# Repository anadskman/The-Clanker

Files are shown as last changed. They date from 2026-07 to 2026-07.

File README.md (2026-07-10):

# The Clanker

# 

# **The Clanker** is a fully custom mechanical keyboard designed from scratch using **KiCad** for the electronics and **Fusion 360** for the case. The goal of this project was to design every part of the keyboard myself, from the schematic and PCB layout to the enclosure and firmware.

The keyboard features a compact 68-key layout, per-key RGB lighting, a rotary encoder, and a 0.91" OLED display, all powered by a Raspberry Pi Pico.

## Features

* 68-key custom layout

* Raspberry Pi Pico (USB-C)

* MX switches

* Per-key SK6812 MINI-E RGB lighting

* Rotary encoder

* 0.91" I²C OLED display

* Custom 3D-printable case

* Designed entirely from scratch

## Design Process
The project began by creating the keyboard layout and designing the schematic in KiCad. After assigning footprints, the PCB was laid out and routed, including the switch matrix, RGB LEDs, OLED display, rotary encoder, and power circuitry.
Once the PCB was complete, it was exported into Fusion 360 where the enclosure was designed around it. The case was built specifically for 3D printing and split into two halves so it could fit on a smaller print bed while remaining rigid once assembled.

## BOM

| Item | Qty | Notes | $ | URL |
| --- | --: | --- | :--:  | ---- |
| Raspberry Pi Pico | 1 | RP2040 microcontroller | 9.23  | [link](https://www.aliexpress.com/item/1005011871301955.html?pdp_ext_f=%7B"order"%3A"19"%2C"eval"%3A"1"%2C"fromPage"%3A"search"%7D) |
| MX Mechanical Switches |  68 | Cherry MX compatible | 30.22 | [link](https://www.aliexpress.com/item/1005008998414457.html?pdp_ext_f=%7B"order"%3A"322"%2C"eval"%3A"1"%2C"fromPage"%3A"search"%7D) |
| PCB Mount Stabilizers  | 4 | For larger keys | 11.23 | [link](https://www.aliexpress.com/item/1005001686299616.html?pdp_ext_f=%7B"order"%3A"267"%2C"eval"%3A"1"%2C"fromPage"%3A"search"%7D) |
| LEDs |  68 | One per switch | 8.68 | [link](https://www.aliexpress.com/item/1005006727416963.html?pdp_ext_f=%7B"order"%3A"59"%2C"spu_best_type"%3A"price"%2C"eval"%3A"1"%2C"fromPage"%3A"search"%7D) |
| Keycap Set | 1 | 68-key compatible | 24.17 | [link](https://www.aliexpress.com/item/1005007252695395.html?pdp_ext_f=%7B"order"%3A"68"%2C"eval"%3A"1"%2C"fromPage"%3A"search"%7D) |
| Rotary Encoder | 1 | EC11 | 9.84 | [link](https://www.aliexpress.com/item/1005011653314162.html?pdp_ext_f=%7B"order"%3A"8"%2C"eval"%3A"1"%2C"fromPage"%3A"search"%7D) |
| Encoder Knob | 1 | Fits encoder shaft | 1.76 | [link](https://www.aliexpress.com/item/1005008291630040.html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"order"%3A"224"%2C"spu_best_type"%3A"price"%2C"eval"%3A"1"%2C"fromPage"%3A"search"%7D&search_p4p_id=20260710071720613074789560480005766622_6) |
| OLED Display | 1 | .91" I2C (SSD1306) | 1.44 | [link](https://www.aliexpress.com/item/1005008997559133.html?pdp_ext_f=%7B"order"%3A"2411"%2C"eval"%3A"1"%2C"fromPage"%3A"search"%7D) |
| PCB | 1 | Custom keyboard PCB | 61.97 | [link](https://github.com/user-attachments/assets/7c825ecb-10aa-4597-84ef-201b4d64e1a1) |
|  |  |  *Shipping* |  *5.71* | |
|  |  |  *Dutes* |  *8.27* |  |
|  |  | **Total** |  **109.56** | |

## Gallery

| PCB | Schematic | CAD Model |
| :---: | :---: | :---: |
|  |  |  |

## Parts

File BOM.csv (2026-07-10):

Item | Quantity | Notes | Price (USD) | URL
Raspberry Pi Pico | 1 | RP2040 microcontroller | 9.23 | https://www.aliexpress.com/item/1005011871301955.html?pdp_ext_f=%7B"order"%3A"19"%2C"eval"%3A"1"%2C"fromPage"%3A"search"%7D
MX Mechanical Switches | 68 | Cherry MX compatible | 30.22 | https://www.aliexpress.com/item/1005008998414457.html?pdp_ext_f=%7B"order"%3A"322"%2C"eval"%3A"1"%2C"fromPage"%3A"search"%7D
PCB Mount Stabilizers | 4 | For larger keys | 11.23 | https://www.aliexpress.com/item/1005001686299616.html?pdp_ext_f=%7B"order"%3A"267"%2C"eval"%3A"1"%2C"fromPage"%3A"search"%7D
LEDs | 68 | One per switch | 8.68 | https://www.aliexpress.com/item/1005006727416963.html?pdp_ext_f=%7B"order"%3A"59"%2C"spu_best_type"%3A"price"%2C"eval"%3A"1"%2C"fromPage"%3A"search"%7D
Keycap Set | 1 | 68-key compatible | 24.17 | https://www.aliexpress.com/item/1005007252695395.html?pdp_ext_f=%7B"order"%3A"68"%2C"eval"%3A"1"%2C"fromPage"%3A"search"%7D
Rotary Encoder | 1 | EC11 | 9.84 | https://www.aliexpress.com/item/1005011653314162.html?pdp_ext_f=%7B"order"%3A"8"%2C"eval"%3A"1"%2C"fromPage"%3A"search"%7D
Encoder Knob | 1 | Fits encoder shaft | 1.76 | https://www.aliexpress.com/item/1005008291630040.html?pdp_ext_f=%7B"order"%3A"224"%2C"spu_best_type"%3A"price"%2C"eval"%3A"1"%2C"fromPage"%3A"search"%7D&search_p4p_id=20260710071720613074789560480005766622_6
OLED Display | 1 | 0.91" I2C (SSD1306) | 1.44 | https://www.aliexpress.com/item/1005008997559133.html?pdp_ext_f=%7B"order"%3A"2411"%2C"eval"%3A"1"%2C"fromPage"%3A"search"%7D
PCB | 1 | Custom keyboard PCB | 61.97 | https://github.com/user-attachments/assets/7c825ecb-10aa-4597-84ef-201b4d64e1a1
 |  | Shipping | 5.71
 |  | Duties | 8.27
 |  | Total | 109.56

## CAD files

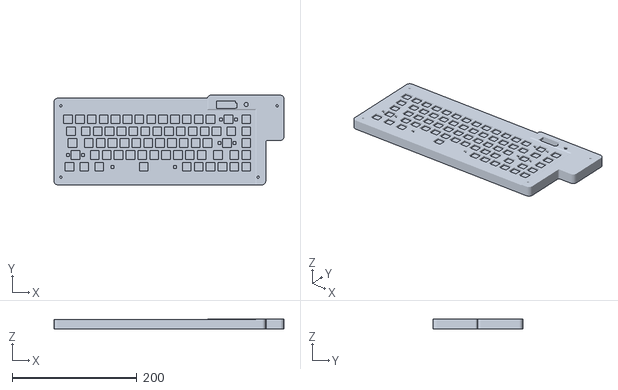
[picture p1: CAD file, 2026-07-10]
CAD/The Clanker Left Base.stl
368.9 x 143.8 x 16.0

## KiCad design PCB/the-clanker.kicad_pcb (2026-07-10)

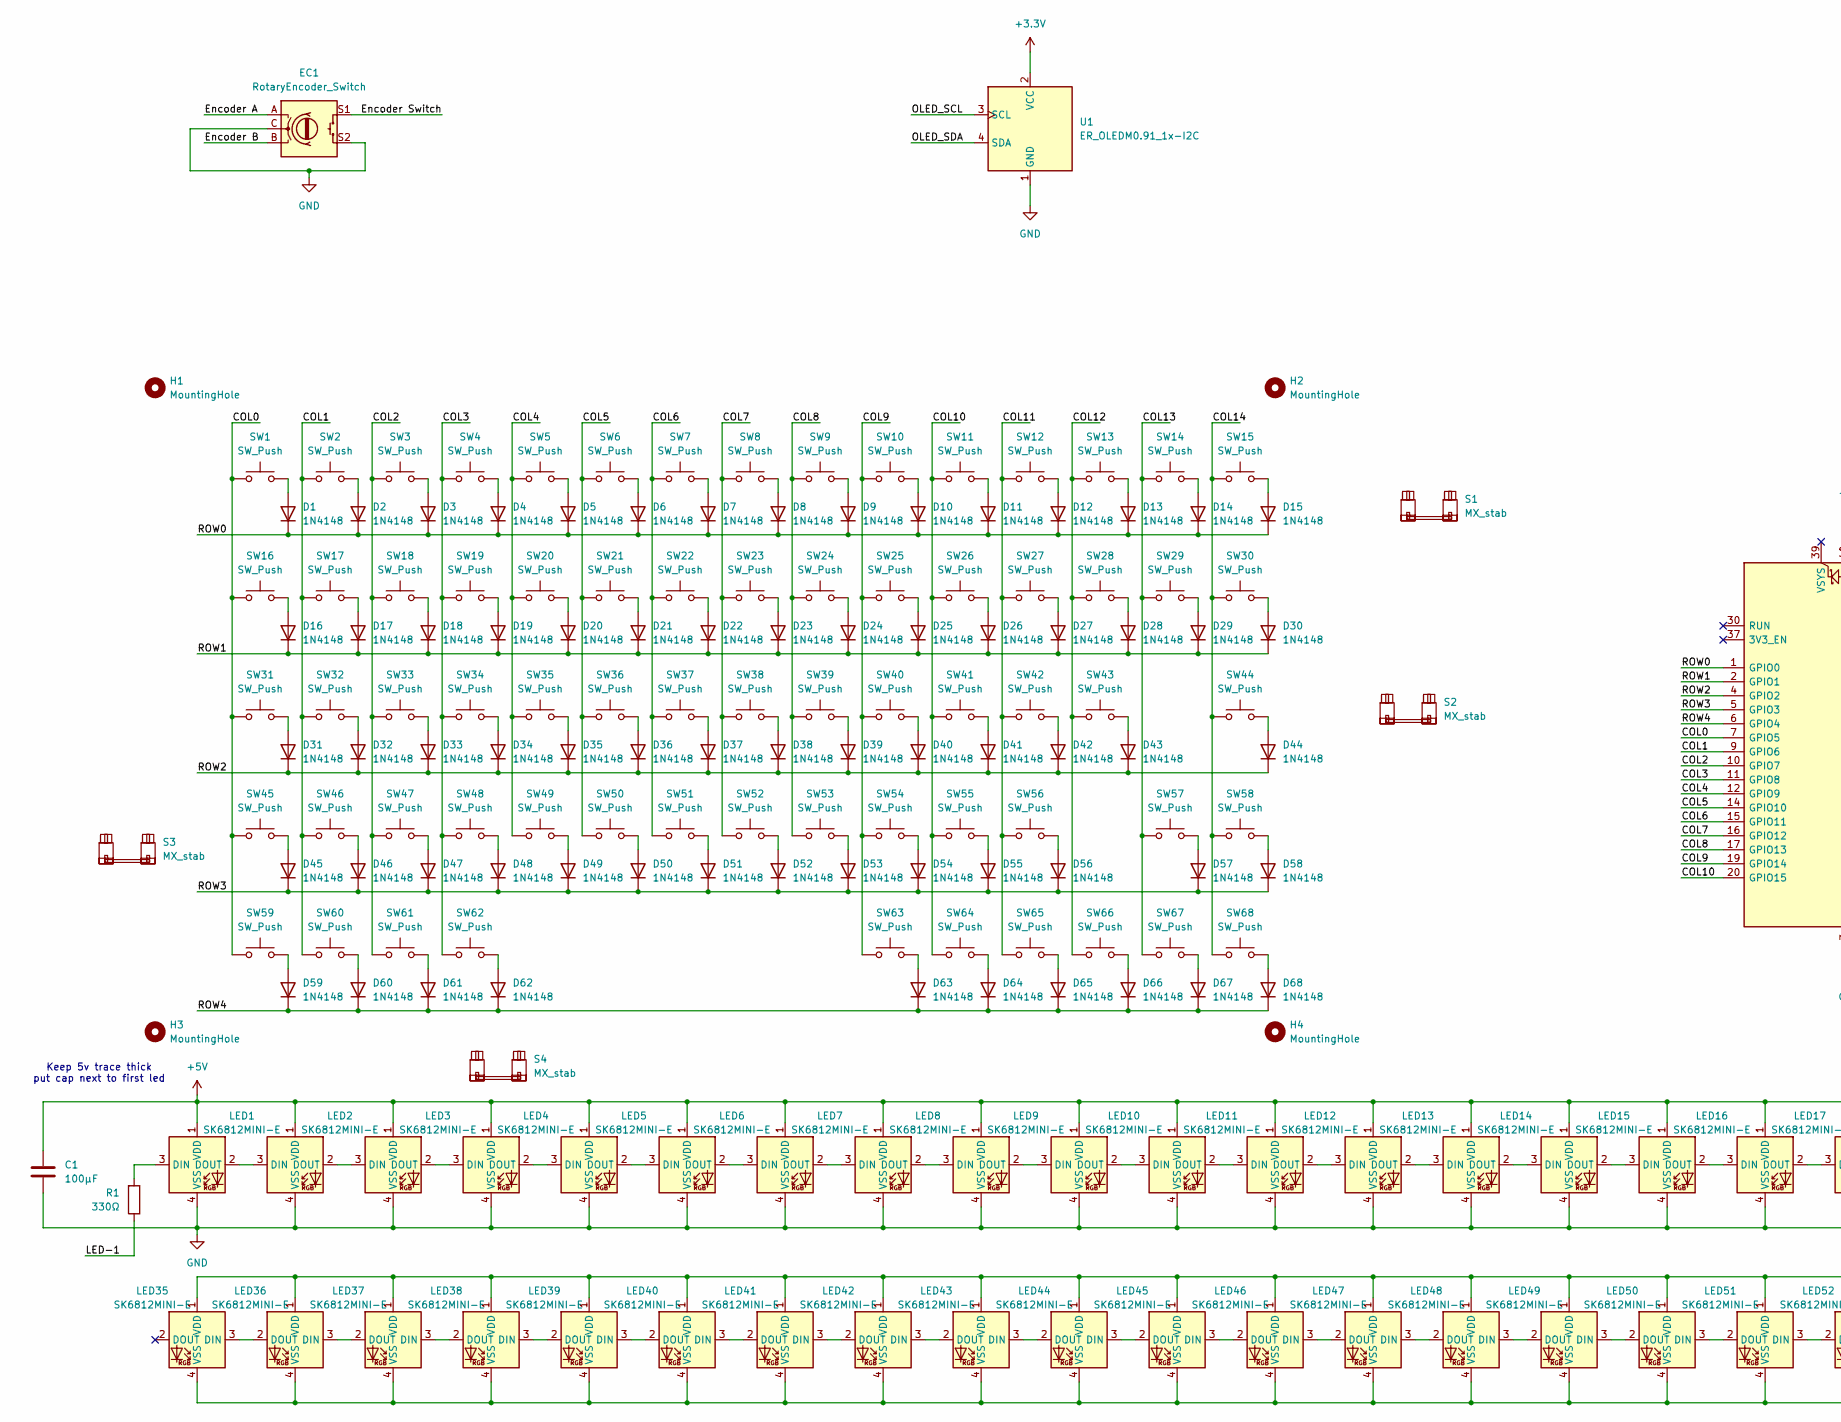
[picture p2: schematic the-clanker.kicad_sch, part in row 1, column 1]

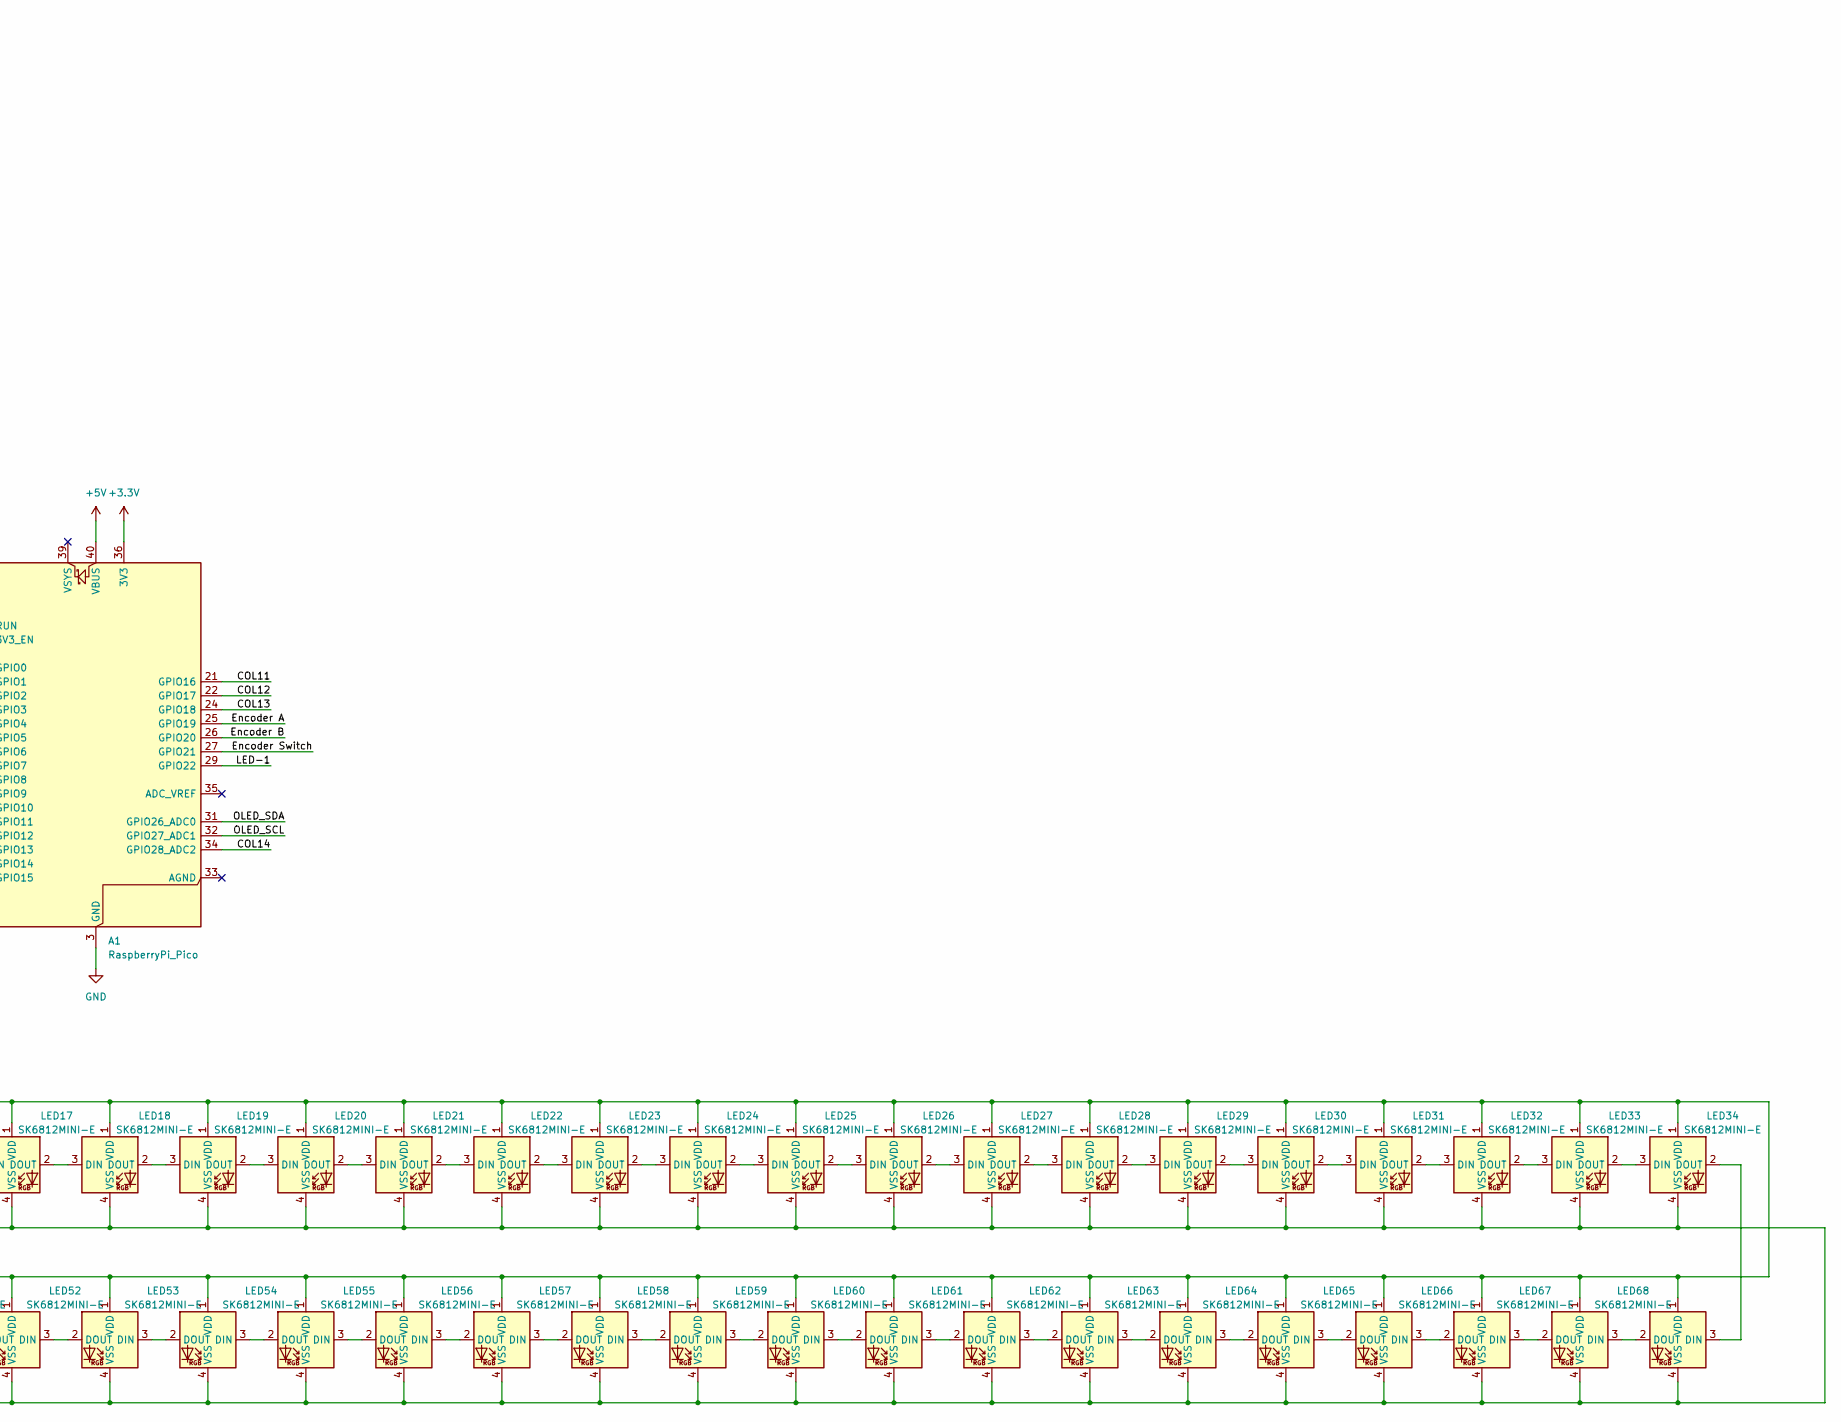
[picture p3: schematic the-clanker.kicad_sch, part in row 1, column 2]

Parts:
A1: RaspberryPi_Pico; RaspberryPi_Pico_Common_THT
C1: 100µF; CP_Radial_D5.0mm_P2.50mm
D1, D2, D3, D4, D5, D6, D7, D8, D9, D10, D11, D12, D13, D14, D15, D16, D17, D18, D19, D20, D21, D22, D23, D24, D25, D26, D27, D28, D29, D30, D31, D32, D33, D34, D35, D36, D37, D38, D39, D40, D41, D42, D43, D44, D45, D46, D47, D48, D49, D50, D51, D52, D53, D54, D55, D56, D57, D58, D59, D60, D61, D62, D63, D64, D65, D66, D67, D68: 1N4148; D_DO-35_SOD27_P7.62mm_Horizontal
EC1: RotaryEncoder_Switch; ROT_Alps_EC11E-Switch
H1, H2, H3, H4: MountingHole; MountingHole_3.2mm_M3
LED1, LED2, LED3, LED4, LED5, LED6, LED7, LED8, LED9, LED10, LED11, LED12, LED13, LED14, LED15, LED16, LED17, LED18, LED19, LED20, LED21, LED22, LED23, LED24, LED25, LED26, LED27, LED28, LED29, LED30, LED31, LED32, LED33, LED34, LED35, LED36, LED37, LED38, LED39, LED40, LED41, LED42, LED43, LED44, LED45, LED46, LED47, LED48, LED49, LED50, LED51, LED52, LED53, LED54, LED55, LED56, LED57, LED58, LED59, LED60, LED61, LED62, LED63, LED64, LED65, LED66, LED67, LED68: SK6812MINI-E; LED_SK6812MINI-E_3.2x2.8mm_P1.5mm_ReverseMount
R1: 330Ω; R_Axial_DIN0207_L6.3mm_D2.5mm_P7.62mm_Horizontal
S1: MX_stab; STAB_MX_2u
S2, S3: MX_stab; STAB_MX_2.25u
S4: MX_stab; STAB_MX_6.25u
SW1, SW2, SW3, SW4, SW5, SW6, SW7, SW8, SW9, SW10, SW11, SW12, SW13, SW14, SW15, SW16, SW17, SW18, SW19, SW20, SW21, SW22, SW23, SW24, SW25, SW26, SW27, SW28, SW29, SW30, SW31, SW32, SW33, SW34, SW35, SW36, SW37, SW38, SW39, SW40, SW41, SW42, SW43, SW44, SW45, SW46, SW47, SW48, SW49, SW50, SW51, SW52, SW53, SW54, SW55, SW56, SW57, SW58, SW59, SW60, SW61, SW62, SW63, SW64, SW65, SW66, SW67, SW68: SW_Push; SW_MX_1u
U1: ER_OLEDM0.91_1x-I2C

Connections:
+3.3V: A1.36 (3V3), U1.2 (VCC)
+5V: A1.40 (VBUS), C1.1, LED1.1 (VDD), LED2.1 (VDD), LED3.1 (VDD), LED4.1 (VDD), LED5.1 (VDD), LED6.1 (VDD), LED7.1 (VDD), LED8.1 (VDD), LED9.1 (VDD), LED10.1 (VDD), LED11.1 (VDD), LED12.1 (VDD), LED13.1 (VDD), LED14.1 (VDD), LED15.1 (VDD), LED16.1 (VDD), LED17.1 (VDD), LED18.1 (VDD), LED19.1 (VDD), LED20.1 (VDD), LED21.1 (VDD), LED22.1 (VDD), LED23.1 (VDD), LED24.1 (VDD), LED25.1 (VDD), LED26.1 (VDD), LED27.1 (VDD), LED28.1 (VDD), LED29.1 (VDD), LED30.1 (VDD), LED31.1 (VDD), LED32.1 (VDD), LED33.1 (VDD), LED34.1 (VDD), LED35.1 (VDD), LED36.1 (VDD), LED37.1 (VDD), LED38.1 (VDD), LED39.1 (VDD), LED40.1 (VDD), LED41.1 (VDD), LED42.1 (VDD), LED43.1 (VDD), LED44.1 (VDD), LED45.1 (VDD), LED46.1 (VDD), LED47.1 (VDD), LED48.1 (VDD), LED49.1 (VDD), LED50.1 (VDD), LED51.1 (VDD), LED52.1 (VDD), LED53.1 (VDD), LED54.1 (VDD), LED55.1 (VDD), LED56.1 (VDD), LED57.1 (VDD), LED58.1 (VDD), LED59.1 (VDD), LED60.1 (VDD), LED61.1 (VDD), LED62.1 (VDD), LED63.1 (VDD), LED64.1 (VDD), LED65.1 (VDD), LED66.1 (VDD), LED67.1 (VDD), LED68.1 (VDD)
/COL0: A1.7 (GPIO5), SW1.1, SW16.1, SW31.1, SW45.1, SW59.1
/COL1: A1.9 (GPIO6), SW2.1, SW17.1, SW32.1, SW46.1, SW60.1
/COL2: A1.10 (GPIO7), SW3.1, SW18.1, SW33.1, SW47.1, SW61.1
/COL3: A1.11 (GPIO8), SW4.1, SW19.1, SW34.1, SW48.1, SW62.1
/COL4: A1.12 (GPIO9), SW5.1, SW20.1, SW35.1, SW49.1
/COL5: A1.14 (GPIO10), SW6.1, SW21.1, SW36.1, SW50.1
/COL6: A1.15 (GPIO11), SW7.1, SW22.1, SW37.1, SW51.1
/COL7: A1.16 (GPIO12), SW8.1, SW23.1, SW38.1, SW52.1
/COL8: A1.17 (GPIO13), SW9.1, SW24.1, SW39.1, SW53.1
/COL9: A1.19 (GPIO14), SW10.1, SW25.1, SW40.1, SW54.1, SW63.1
/COL10: A1.20 (GPIO15), SW11.1, SW26.1, SW41.1, SW55.1, SW64.1
/COL11: A1.21 (GPIO16), SW12.1, SW27.1, SW42.1, SW56.1, SW65.1
/COL12: A1.22 (GPIO17), SW13.1, SW28.1, SW43.1, SW66.1
/COL13: A1.24 (GPIO18), SW14.1, SW29.1, SW57.1, SW67.1
/COL14: A1.34 (GPIO28_ADC2), SW15.1, SW30.1, SW44.1, SW58.1, SW68.1
/Encoder A: A1.25 (GPIO19), EC1.A
/Encoder B: A1.26 (GPIO20), EC1.B
/Encoder Switch: A1.27 (GPIO21), EC1.S1
/LED-1: A1.29 (GPIO22), R1.1
/OLED_SCL: A1.32 (GPIO27_ADC1), U1.3 (SCL)
/OLED_SDA: A1.31 (GPIO26_ADC0), U1.4 (SDA)
/ROW0: A1.1 (GPIO0), D1.1 (K), D2.1 (K), D3.1 (K), D4.1 (K), D5.1 (K), D6.1 (K), D7.1 (K), D8.1 (K), D9.1 (K), D10.1 (K), D11.1 (K), D12.1 (K), D13.1 (K), D14.1 (K), D15.1 (K)
/ROW1: A1.2 (GPIO1), D16.1 (K), D17.1 (K), D18.1 (K), D19.1 (K), D20.1 (K), D21.1 (K), D22.1 (K), D23.1 (K), D24.1 (K), D25.1 (K), D26.1 (K), D27.1 (K), D28.1 (K), D29.1 (K), D30.1 (K)
/ROW2: A1.4 (GPIO2), D31.1 (K), D32.1 (K), D33.1 (K), D34.1 (K), D35.1 (K), D36.1 (K), D37.1 (K), D38.1 (K), D39.1 (K), D40.1 (K), D41.1 (K), D42.1 (K), D43.1 (K), D44.1 (K)
/ROW3: A1.5 (GPIO3), D45.1 (K), D46.1 (K), D47.1 (K), D48.1 (K), D49.1 (K), D50.1 (K), D51.1 (K), D52.1 (K), D53.1 (K), D54.1 (K), D55.1 (K), D56.1 (K), D57.1 (K), D58.1 (K)
/ROW4: A1.6 (GPIO4), D59.1 (K), D60.1 (K), D61.1 (K), D62.1 (K), D63.1 (K), D64.1 (K), D65.1 (K), D66.1 (K), D67.1 (K), D68.1 (K)
GND: A1.3 (GND), A1.8 (GND), A1.13 (GND), A1.18 (GND), A1.23 (GND), A1.28 (GND), A1.38 (GND), C1.2, EC1.C, EC1.S2, LED1.4 (VSS), LED2.4 (VSS), LED3.4 (VSS), LED4.4 (VSS), LED5.4 (VSS), LED6.4 (VSS), LED7.4 (VSS), LED8.4 (VSS), LED9.4 (VSS), LED10.4 (VSS), LED11.4 (VSS), LED12.4 (VSS), LED13.4 (VSS), LED14.4 (VSS), LED15.4 (VSS), LED16.4 (VSS), LED17.4 (VSS), LED18.4 (VSS), LED19.4 (VSS), LED20.4 (VSS), LED21.4 (VSS), LED22.4 (VSS), LED23.4 (VSS), LED24.4 (VSS), LED25.4 (VSS), LED26.4 (VSS), LED27.4 (VSS), LED28.4 (VSS), LED29.4 (VSS), LED30.4 (VSS), LED31.4 (VSS), LED32.4 (VSS), LED33.4 (VSS), LED34.4 (VSS), LED35.4 (VSS), LED36.4 (VSS), LED37.4 (VSS), LED38.4 (VSS), LED39.4 (VSS), LED40.4 (VSS), LED41.4 (VSS), LED42.4 (VSS), LED43.4 (VSS), LED44.4 (VSS), LED45.4 (VSS), LED46.4 (VSS), LED47.4 (VSS), LED48.4 (VSS), LED49.4 (VSS), LED50.4 (VSS), LED51.4 (VSS), LED52.4 (VSS), LED53.4 (VSS), LED54.4 (VSS), LED55.4 (VSS), LED56.4 (VSS), LED57.4 (VSS), LED58.4 (VSS), LED59.4 (VSS), LED60.4 (VSS), LED61.4 (VSS), LED62.4 (VSS), LED63.4 (VSS), LED64.4 (VSS), LED65.4 (VSS), LED66.4 (VSS), LED67.4 (VSS), LED68.4 (VSS), U1.1 (GND)
unnamed: D1.2 (A), SW1.2
unnamed: D2.2 (A), SW2.2
unnamed: D3.2 (A), SW3.2
unnamed: D4.2 (A), SW4.2
unnamed: D5.2 (A), SW5.2
unnamed: D6.2 (A), SW6.2
unnamed: D7.2 (A), SW7.2
unnamed: D8.2 (A), SW8.2
unnamed: D9.2 (A), SW9.2
unnamed: D10.2 (A), SW10.2
unnamed: D11.2 (A), SW11.2
unnamed: D12.2 (A), SW12.2
unnamed: D13.2 (A), SW13.2
unnamed: D14.2 (A), SW14.2
unnamed: D15.2 (A), SW15.2
unnamed: D16.2 (A), SW16.2
unnamed: D17.2 (A), SW17.2
unnamed: D18.2 (A), SW18.2
unnamed: D19.2 (A), SW19.2
unnamed: D20.2 (A), SW20.2
unnamed: D21.2 (A), SW21.2
unnamed: D22.2 (A), SW22.2
unnamed: D23.2 (A), SW23.2
unnamed: D24.2 (A), SW24.2
unnamed: D25.2 (A), SW25.2
unnamed: D26.2 (A), SW26.2
unnamed: D27.2 (A), SW27.2
unnamed: D28.2 (A), SW28.2
unnamed: D29.2 (A), SW29.2
unnamed: D30.2 (A), SW30.2
unnamed: D31.2 (A), SW31.2
unnamed: D32.2 (A), SW32.2
unnamed: D33.2 (A), SW33.2
unnamed: D34.2 (A), SW34.2
unnamed: D35.2 (A), SW35.2
unnamed: D36.2 (A), SW36.2
unnamed: D37.2 (A), SW37.2
unnamed: D38.2 (A), SW38.2
unnamed: D39.2 (A), SW39.2
unnamed: D40.2 (A), SW40.2
unnamed: D41.2 (A), SW41.2
unnamed: D42.2 (A), SW42.2
unnamed: D43.2 (A), SW43.2
unnamed: D44.2 (A), SW44.2
unnamed: D45.2 (A), SW45.2
unnamed: D46.2 (A), SW46.2
unnamed: D47.2 (A), SW47.2
unnamed: D48.2 (A), SW48.2
unnamed: D49.2 (A), SW49.2
unnamed: D50.2 (A), SW50.2
unnamed: D51.2 (A), SW51.2
unnamed: D52.2 (A), SW52.2
unnamed: D53.2 (A), SW53.2
unnamed: D54.2 (A), SW54.2
unnamed: D55.2 (A), SW55.2
unnamed: D56.2 (A), SW56.2
unnamed: D57.2 (A), SW57.2
unnamed: D58.2 (A), SW58.2
unnamed: D59.2 (A), SW59.2
unnamed: D60.2 (A), SW60.2
unnamed: D61.2 (A), SW61.2
unnamed: D62.2 (A), SW62.2
unnamed: D63.2 (A), SW63.2
unnamed: D64.2 (A), SW64.2
unnamed: D65.2 (A), SW65.2
unnamed: D66.2 (A), SW66.2
unnamed: D67.2 (A), SW67.2
unnamed: D68.2 (A), SW68.2
unnamed: LED1.3 (DIN), R1.2
unnamed: LED1.2 (DOUT), LED2.3 (DIN)
unnamed: LED2.2 (DOUT), LED3.3 (DIN)
unnamed: LED3.2 (DOUT), LED4.3 (DIN)
unnamed: LED4.2 (DOUT), LED5.3 (DIN)
unnamed: LED5.2 (DOUT), LED6.3 (DIN)
unnamed: LED6.2 (DOUT), LED7.3 (DIN)
unnamed: LED7.2 (DOUT), LED8.3 (DIN)
unnamed: LED8.2 (DOUT), LED9.3 (DIN)
unnamed: LED9.2 (DOUT), LED10.3 (DIN)
unnamed: LED10.2 (DOUT), LED11.3 (DIN)
unnamed: LED11.2 (DOUT), LED12.3 (DIN)
unnamed: LED12.2 (DOUT), LED13.3 (DIN)
unnamed: LED13.2 (DOUT), LED14.3 (DIN)
unnamed: LED14.2 (DOUT), LED15.3 (DIN)
unnamed: LED15.2 (DOUT), LED16.3 (DIN)
unnamed: LED16.2 (DOUT), LED17.3 (DIN)
unnamed: LED17.2 (DOUT), LED18.3 (DIN)
unnamed: LED18.2 (DOUT), LED19.3 (DIN)
unnamed: LED19.2 (DOUT), LED20.3 (DIN)
unnamed: LED20.2 (DOUT), LED21.3 (DIN)
unnamed: LED21.2 (DOUT), LED22.3 (DIN)
unnamed: LED22.2 (DOUT), LED23.3 (DIN)
unnamed: LED23.2 (DOUT), LED24.3 (DIN)
unnamed: LED24.2 (DOUT), LED25.3 (DIN)
unnamed: LED25.2 (DOUT), LED26.3 (DIN)
unnamed: LED26.2 (DOUT), LED27.3 (DIN)
unnamed: LED27.2 (DOUT), LED28.3 (DIN)
unnamed: LED28.2 (DOUT), LED29.3 (DIN)
unnamed: LED29.2 (DOUT), LED30.3 (DIN)
unnamed: LED30.2 (DOUT), LED31.3 (DIN)
unnamed: LED31.2 (DOUT), LED32.3 (DIN)
unnamed: LED32.2 (DOUT), LED33.3 (DIN)
unnamed: LED33.2 (DOUT), LED34.3 (DIN)
unnamed: LED34.2 (DOUT), LED68.3 (DIN)
unnamed: LED35.3 (DIN), LED36.2 (DOUT)
unnamed: LED36.3 (DIN), LED37.2 (DOUT)
unnamed: LED37.3 (DIN), LED38.2 (DOUT)
unnamed: LED38.3 (DIN), LED39.2 (DOUT)
unnamed: LED39.3 (DIN), LED40.2 (DOUT)
unnamed: LED40.3 (DIN), LED41.2 (DOUT)
unnamed: LED41.3 (DIN), LED42.2 (DOUT)
unnamed: LED42.3 (DIN), LED43.2 (DOUT)
unnamed: LED43.3 (DIN), LED44.2 (DOUT)
unnamed: LED44.3 (DIN), LED45.2 (DOUT)
unnamed: LED45.3 (DIN), LED46.2 (DOUT)
unnamed: LED46.3 (DIN), LED47.2 (DOUT)
unnamed: LED47.3 (DIN), LED48.2 (DOUT)
unnamed: LED48.3 (DIN), LED49.2 (DOUT)
unnamed: LED49.3 (DIN), LED50.2 (DOUT)
unnamed: LED50.3 (DIN), LED51.2 (DOUT)
unnamed: LED51.3 (DIN), LED52.2 (DOUT)
unnamed: LED52.3 (DIN), LED53.2 (DOUT)
unnamed: LED53.3 (DIN), LED54.2 (DOUT)
unnamed: LED54.3 (DIN), LED55.2 (DOUT)
unnamed: LED55.3 (DIN), LED56.2 (DOUT)
unnamed: LED56.3 (DIN), LED57.2 (DOUT)
unnamed: LED57.3 (DIN), LED58.2 (DOUT)
unnamed: LED58.3 (DIN), LED59.2 (DOUT)
unnamed: LED59.3 (DIN), LED60.2 (DOUT)
unnamed: LED60.3 (DIN), LED61.2 (DOUT)
unnamed: LED61.3 (DIN), LED62.2 (DOUT)
unnamed: LED62.3 (DIN), LED63.2 (DOUT)
unnamed: LED63.3 (DIN), LED64.2 (DOUT)
unnamed: LED64.3 (DIN), LED65.2 (DOUT)
unnamed: LED65.3 (DIN), LED66.2 (DOUT)
unnamed: LED66.3 (DIN), LED67.2 (DOUT)
unnamed: LED67.3 (DIN), LED68.2 (DOUT)

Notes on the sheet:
Keep 5v trace thick put cap next to first led

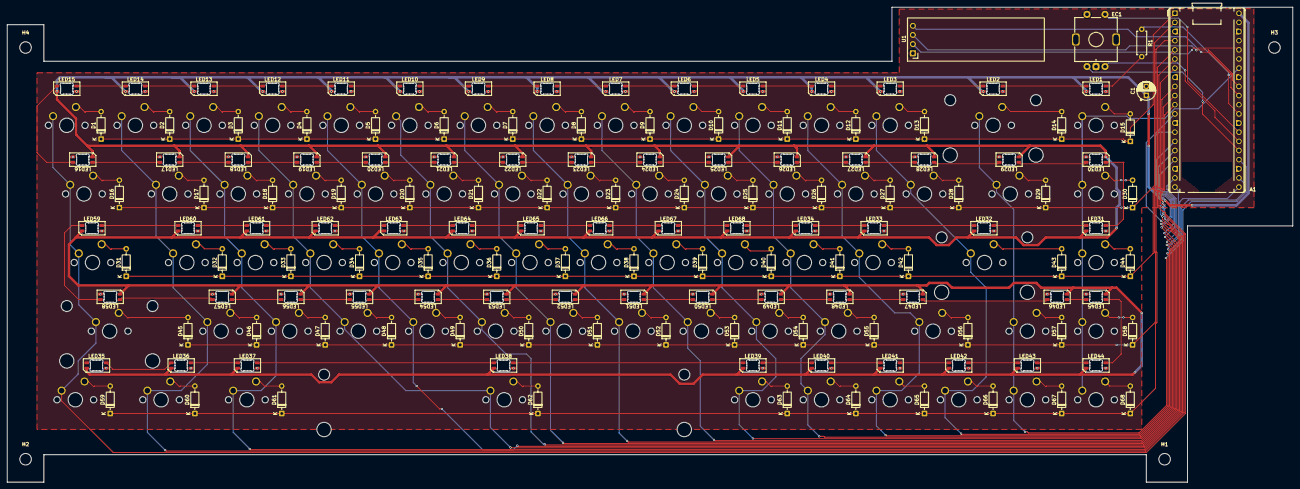
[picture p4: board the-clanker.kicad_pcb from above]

Board: 2 copper layers, 356.9 x 131.8 mm, 217 parts (0 on the bottom side), 165 nets.

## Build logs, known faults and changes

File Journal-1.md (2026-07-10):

# **Journal 1**

## *05/07/26 14:30 - 18:00*

## **The Plan + Schematic**

### **Theme**

I choose the name **"The Clanker"**

##### **Colors**

* Case: Sage green (#94B7AC)
* Keycaps: White
* Accent key (Esc or Enter): muted gray
* Knob: White or brushed aluminum
* RGB: Warm white by default with customizable effects

### **Plan**

#### **Features**

* Per-key RGB
* Rotary encoder
* 0.91" OLED
* USB-C (Pico)
* Silkscreen artwork
* Hot Swappable

#### **Keyboard Layout**

*5 row × 16 column matrix*

**Row0(*Numbers*)**

| Key       | Row | Col |

| --------- | --- | --- |

| Esc       | R0  | C0  |

| 1         | R0  | C1  |

| 2         | R0  | C2  |

| 3         | R0  | C3  |

| 4         | R0  | C4  |

| 5         | R0  | C5  |

| 6         | R0  | C6  |

| 7         | R0  | C7  |

| 8         | R0  | C8  |

| 9         | R0  | C9  |

| 0         | R0  | C10 |

| -         | R0  | C11 |

| =         | R0  | C12 |

| Backspace | R0  | C13 |

| Del       | R0  | C14 |

**Row1(*Q*)**

| Key | Row | Col |

| --- | --- | --- |

| Tab | R1  | C0  |

| Q   | R1  | C1  |

| W   | R1  | C2  |

| E   | R1  | C3  |

| R   | R1  | C4  |

| T   | R1  | C5  |

| Y   | R1  | C6  |

| U   | R1  | C7  |

| I   | R1  | C8  |

| O   | R1  | C9  |

| P   | R1  | C10 |

| \[   | R1  | C11 |

| ]   | R1  | C12 |

| \\   | R1  | C13 |

| `   | R1  | C14 |

**Row2(*Home*)**

| Key   | Row | Col |

| ----- | --- | --- |

| Caps  | R2  | C0  |

| A     | R2  | C1  |

| S     | R2  | C2  |

| D     | R2  | C3  |

| F     | R2  | C4  |

| G     | R2  | C5  |

| H     | R2  | C6  |

| J     | R2  | C7  |

| K     | R2  | C8  |

| L     | R2  | C9  |

| ;     | R2  | C10 |

| '     | R2  | C11 |

| Enter | R2  | C12 |

| pgup  | R2  | C14 |

**Row3(*Shift*)**

| Key   | Row | Col |

| ----- | --- | --- |

| Shift | R3  | C0  |

| Z     | R3  | C1  |

| X     | R3  | C2  |

| C     | R3  | C3  |

| V     | R3  | C4  |

| B     | R3  | C5  |

| N     | R3  | C6  |

| M     | R3  | C7  |

| ,     | R3  | C8  |

| .     | R3  | C9  |

| /     | R3  | C10 |

| Shift | R3  | C11 |

| ↑     | R3  | C13 |

| pgdn  | R3  | C14 |

**Row4(*Bottom*)**

| Key    | Row | Col |

| -----  | --- | --- |

| Ctrl   | R4  | C0  |

| Win    | R4  | C1  |

| Alt    | R4  | C2  |

| Space  | R4  | C3  |

| Alt gr | R4  | C9  |

| Fn     | R4  | C10 |

| Ctrl   | R4  | C11 |

| ←      | R4  | C12 |

| ↓      | R4  | C13 |

| →      | R4  | C14 |

I started by placing the pico, and a single switch with diode

Once I had the keyboard layout figured out I copied and paste each switch and diode, making the matrix. Then I used net labels to connect to pico, GP0-GP18.

I added 4 mounting holes on the conners of whole matrix.

After this I wired the Oled and Encoder,
Encoder A - GP19

Encoder B - GP20

Encoder Switch - GP21

OLED SDA - GP26

OLED SCL - GP27

Then I Wired up the SK6812 MINI-E. I place 17 of them *(I'll Copy the rest in the PCB)* I connected the first led to GP22 and then put the rest in series.

I connect them all to 5v and gnd and put a 100µF capacitor on those rails.

I also put a 330Ω Resistor on the first led to the Pico.

Lastly I Annotated the schematic

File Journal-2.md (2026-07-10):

# **Journal-2**

## *05/07/26 19:00 - 22:00*

## *06/07/26 12:00 - 16:00*

## *Total:* \~**7**hrs

## **Footprints + PCB**

#### **Footprints**

* Pico - RaspberryPi\_Pico\_Common\_THT
* Diodes - Diode\_THT:D\_DO-35\_SOD27\_P7.62mm\_Horizontal
* Switches - PCM\_marbastlib-mx:SW\_MX\_1u
* Stabilizers - PCM\_marbastlib-mx:STAB\_MX\_P\_2.25u
* Mounting Holes - MountingHole\_3.2mm\_M3
* LEDs - LED\_SK6812MINI-E
* Rotary - PCM\_marbastlib-various:ROT\_Alps\_EC11E-Switch
* OLED - Display:ER\_OLEDM0.91\_1x-I2C
* Resistor - Resistor\_THT:R\_Axial\_DIN0207\_L6.3mm\_D2.5mm\_P7.62mm\_Horizontal
* Cap - Capacitor\_THT:CP\_Radial\_D5.0mm\_P2.50mm

### **PCB**

I after I assigned the footprints I set my scale to 19.05mm(1u) and tried placing all the keys and stabs.
however for some reason it didn't look right and wasn't lining up right.

I updated Matrix as it wasn't quite how I wanted, but this turned out to be good as I noticed the cols were wired into the rows instead of across.

I also updated the stabs footprints so space is 6.25u, and then 2x 2.25u and a 2u.
I also added grid for .25u, .5u, and .75u and this made it a lot easier to layout they keys. I even added .125u.

I indent row1 by .25u, row2 by .5u, and row3 by .75u.

After all the keys and stabs were placed I test where I want the pico.

I originally had it on the right but since I wanted the rotary and oled on the top left corner I ended up moving it over there.

Then I placed all the diodes out which took for ever, along with the Leds but I put the Leds in B.Cu by pressing `f` and placed them just under the keys.

But after thinking about it I moved each led back to F.Cu and put them in-between the keys

I moved the pico back the right side as my pc sits on the right.

I then slowly routed everything, the leds I had to rotate them all 180 deg ivdivulialy so the in out pins align.
But for some reason every so led was in the wrong place, for example 10, 12, 11, instead of 10, 11, 12. which messes with the routed so I tried fixing it.

But I think the problem was in the schematic I only made 17 leds and in the pcb just copied them over, so Instead I made all 68 led in the schematic and slowly put the new ones in place.

Once the leds were wired up to resistor and pico I did the oled a encoder signal pins.

Finally all the GPIO pins are done.

Now Gnd, 3.3v and 5v.

For Gnd im just doing a gnd fill

5v for I used .7mm tracks as there is a lot of stuff on them

I ran DRC but its giving me 330+ errors about thermal, unconnections, ect.

so I spent maybe 30mins atleast fixing, and debugging all of it.

I solved a fair bit of it and the rest are not to worry about(Hopefully)

**Row0(*Numbers*)**

| Key       | Row | Col |

| --------- | --- | --- |

| Esc       | R0  | C0  |

| 1         | R0  | C1  |

| 2         | R0  | C2  |

| 3         | R0  | C3  |

| 4         | R0  | C4  |

| 5         | R0  | C5  |

| 6         | R0  | C6  |

| 7         | R0  | C7  |

| 8         | R0  | C8  |

| 9         | R0  | C9  |

| 0         | R0  | C10 |

| -         | R0  | C11 |

| =         | R0  | C12 |

| Backspace | R0  | C13 |

| Del       | R0  | C14 |

**Row1(*Q*)**

| Key | Row | Col |

| --- | --- | --- |

| Tab | R1  | C0  |

| Q   | R1  | C1  |

| W   | R1  | C2  |

| E   | R1  | C3  |

| R   | R1  | C4  |

| T   | R1  | C5  |

| Y   | R1  | C6  |

| U   | R1  | C7  |

| I   | R1  | C8  |

| O   | R1  | C9  |

| P   | R1  | C10 |

| \[   | R1  | C11 |

| ]   | R1  | C12 |

| \\   | R1  | C13 |

| `   | R1  | C14 |

**Row2(*Home*)**

| Key   | Row | Col |

| ----- | --- | --- |

| Caps  | R2  | C0  |

| A     | R2  | C1  |

| S     | R2  | C2  |

| D     | R2  | C3  |

| F     | R2  | C4  |

| G     | R2  | C5  |

| H     | R2  | C6  |

| J     | R2  | C7  |

| K     | R2  | C8  |

| L     | R2  | C9  |

| ;     | R2  | C10 |

| '     | R2  | C11 |

| Enter | R2  | C12 |

| pgup  | R2  | C14 |

**Row3(*Shift*)**

| Key   | Row | Col |

| ----- | --- | --- |

| Shift | R3  | C0  |

| Z     | R3  | C1  |

| X     | R3  | C2  |

| C     | R3  | C3  |

| V     | R3  | C4  |

| B     | R3  | C5  |

| N     | R3  | C6  |

| M     | R3  | C7  |

| ,     | R3  | C8  |

| .     | R3  | C9  |

| /     | R3  | C10 |

| Shift | R3  | C11 |

| ↑     | R3  | C13 |

| pgdn  | R3  | C14 |

**Row4(*Bottom*)**

| Key    | Row | Col |

| -----  | --- | --- |

| Ctrl   | R4  | C0  |

| Win    | R4  | C1  |

| Alt    | R4  | C2  |

| Space  | R4  | C3  |

| Alt gr | R4  | C9  |

| Fn     | R4  | C10 |

| Ctrl   | R4  | C11 |

| ←      | R4  | C12 |

| ↓      | R4  | C13 |

| →      | R4  | C14 |

| Offset |       Distance |

| ------ | -------------: |

| 0.25u  |  \*\*4.7625 mm\*\* |

| 0.5u   |   \*\*9.525 mm\*\* |

| 0.75u  | \*\*14.2875 mm\*\* |

| 1u     |   \*\*19.05 mm\*\* |

look through chat for what progress - basically everything pcb, redesign as it wasn't working, added keys to schematic

If your footprint only has 3 pads → WRONG version.

Orientation rule:

All LEDs must face the same direction OR follow chain direction.

We’ll handle rotation later in PCB stage.

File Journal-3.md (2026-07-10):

# **Journal-3**

## *06/07/26 20:00 - 22:00*

## *07/07/26 10:00 - 16:00*

## **CAD/PCB Redesign**

#### **CAD**

I know the guide uses onshape but I personally think **fusion 360** is so much nicer to work with, so that's what I'll be using.

I started by exporting my pcb as a `.step` and then setting up my cad workspace.

I imported the `the-clanker-pcb.step` and outlined how I want the case to look with a 4mm gap from the pcb all over.

once the case was made I uploaded a .step of cherry mx keycaps and place every single one, all 68...
and then I raised the pcb into position in the case.

#### **Next Day (PCB)**

I ended up remaking the whole case in a new document as the last one was just too messy for my liking.

I also slightly fixed the positioning of some keys, for example caps lock was 1mm off so I fixed that.

I actually decided to redo the whole pcb because I could do I lot better and the current look is kinda... pathetic.

so I started by going to `https://www.keyboard-layout-editor.com` and design the keyboard and following that design into the pcb.

Id say this went a lot quicker because I had the design right Infront of me and I already understood what to do by this point.

Eventually I had the new design laid out and start to route everything.

This took for ever because, some how the keys were in wrong places like sw68 being where sw15 should be, and that took a while along with fixing all the diodes too.

At least the routing was quick and **much** tidier than before.

Once I had everything for the pcb done I ran a quick *(it took 4 mins)* DRC, there were over 250 errors but most were just clearance so actually only 2 errors about thermal, and then 58 about led grounds not connected to ground fill.

I added vias on the gnds of the leds and ran drc again...
only 1 error and its thermal but i cant do anything about it so its fine.

##### **Tomorrow**

* ##### 3d models on pcb *(est. 1-2hrs)*
* ##### CAD *(est. 3hrs)*

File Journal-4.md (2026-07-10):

# **Journal-4**

## *08/07/26 10:00 - 12:00*

## 09/07/26 18:00 - 18:45

## **CAD/PCB Models**

#### **PCB Models**

I installed a keyboard switch models plugin in the plugin manager.

This meant in the pcb I can select each switch and set its switch and stablisers and it would be auto aligned.

Once all the models were on the board except the keys, I exported everything and uploaded the step to fusion and started the case.

I finished placing all the keycaps and then i decided to make the keys part of the case lower than the rest.

Once I finished the basics of the case I cut the keyboard in half as it is too big for my 3d printer.

I just made a mid plane and cut the board in half and added 9x9mm square top and bottom for the left and right sides to be glued together.

The mounting holes would also hold them together going through the pcb.

Lastly I finished exporting everything and uploaded everything to GitHub.

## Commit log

2026-07-10 Modify keyboard configuration for new model
    Updated keyboard configuration with new name, product details, and matrix pin assignments.
2026-07-10 Add BOM.csv with component details and pricing
    [BOM.csv]
